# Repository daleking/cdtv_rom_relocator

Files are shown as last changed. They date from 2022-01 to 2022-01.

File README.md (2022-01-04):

# CDTV Extended ROM and CPU Relocator

I wanted to use a single 27C400 for the extended ROM in my CDTV because 2x
27C1000's are a pain.  A single socket for the rom also makes debugging easier
because I can use a single flashed based rom.  This means I can easily pop in
[CDTV Land's replacement ROM](https://cdtvland.com/os235/) and easily burn or
test future updates.

The second goal was to relocate the CPU socket in such a way to allow an
accelerator such as a TF536 or 020-TK to be installed without interferring with
caps and in such a way that by soldering everything together the case for the
CDTV could still be closed.

Hence the CDTV ROM Relocator was born.  It's a simple relocator with some
decoding logic for the extended ROM and a jumper to disable/enable the rom
(since JP15 on the motherboard only drives logic to the motherboard roms).

By trimming the CPU pins and soldering together a sandwich, the case can be
closed.

If you want to build one you can try the [gerbers from
here](CDTV_Reromlocator/gerbers_v3.zip).

## Photos

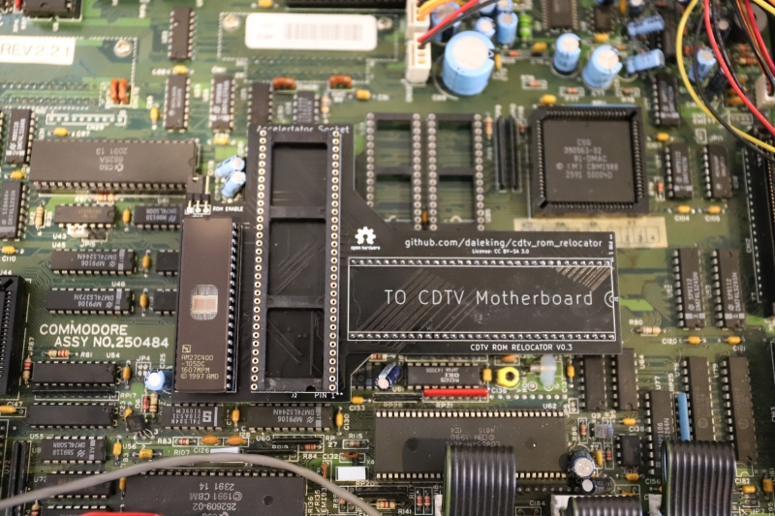
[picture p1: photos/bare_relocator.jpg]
bare relocator


This is the bare relocator with an empty 68000 socket.  Installing the original
68000 will still work and the case can still be closed.

**Note!**  If you install a socket for the accelerator you will likely not be able
to close the case.  I recommend soldering the accelerator directly to the
relocator but please do this at your own risk!

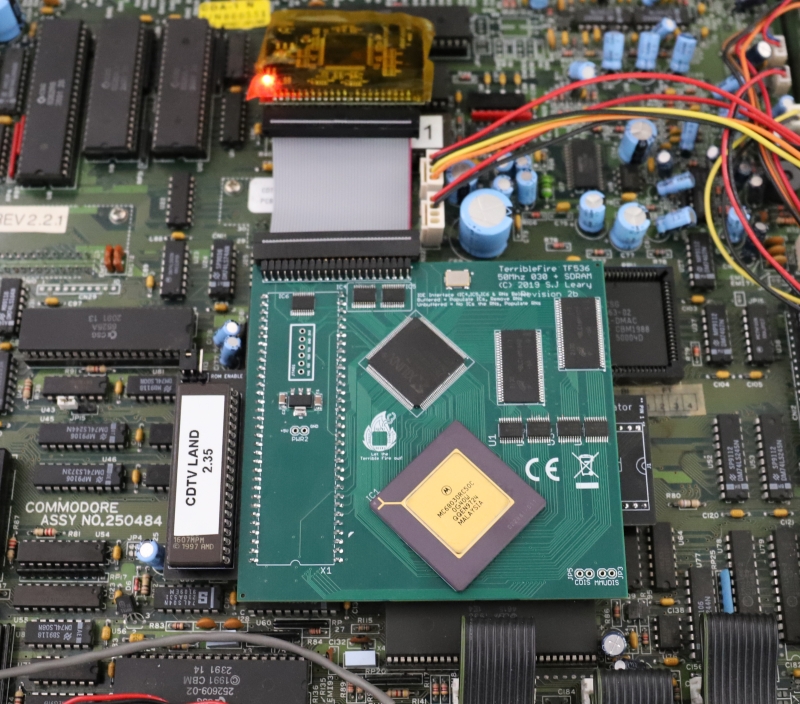
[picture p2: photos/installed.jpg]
installed


Here we have an installed TF536 and CDTV OS 2.35 on a single 27C400.

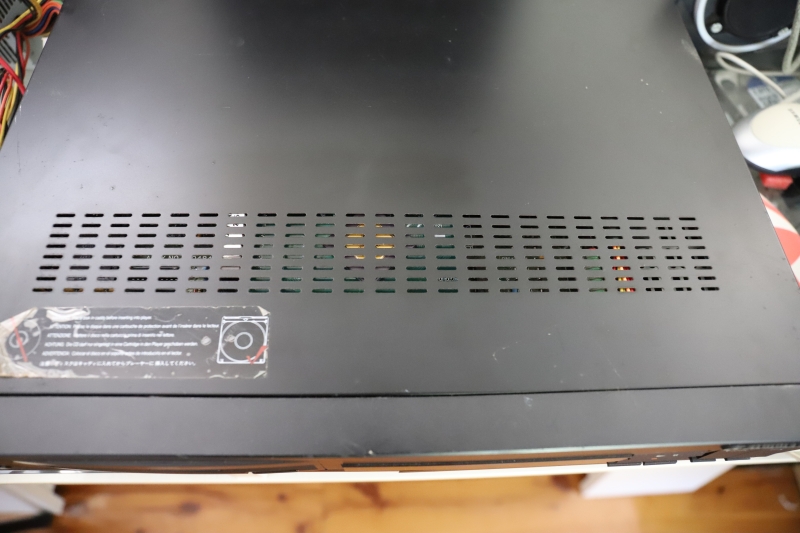
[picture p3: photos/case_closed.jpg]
case closed


Case closed!  The tallest component is the ROM, which still has a mm or two
before it touches the case.

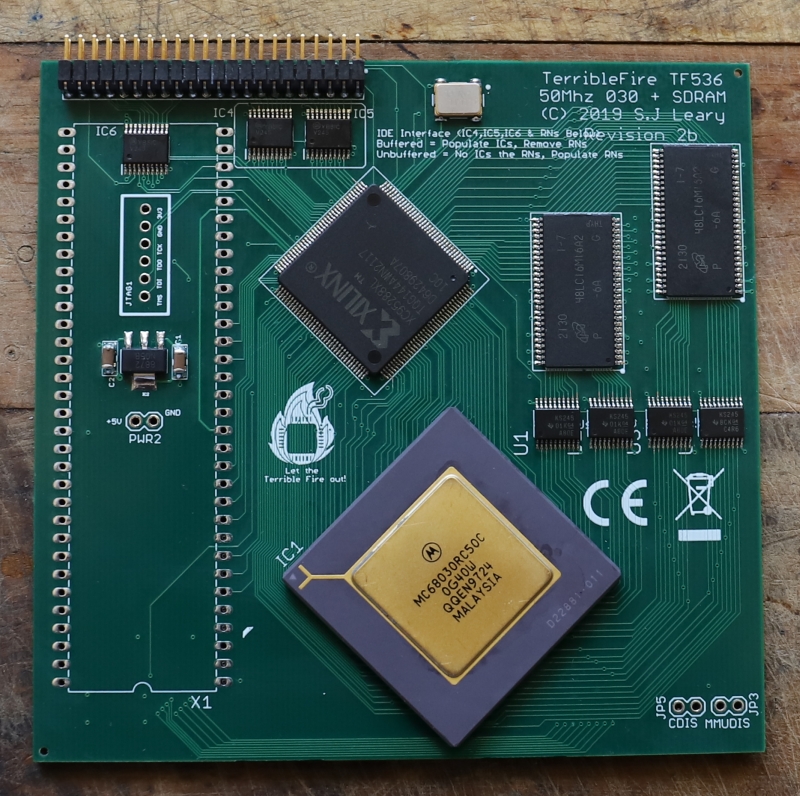
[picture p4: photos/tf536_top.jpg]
tf526 top


We'll need an accelerator.  I like the TF536 with the [firmware from
here](https://www.exxoshost.co.uk/forum/viewtopic.php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)
which disables the flashy boot rom on the TF536 (that is in the same address
space as the extended ROM).

You will also want a right angled IDE header, not a straight one.  This means
the cable connector is nice and flat.

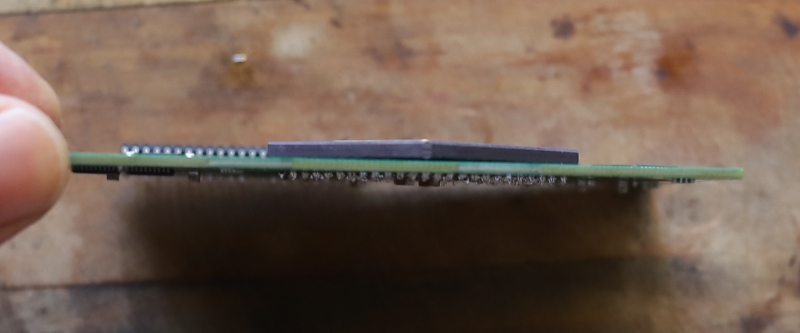
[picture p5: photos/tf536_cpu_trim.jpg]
tf536 cpu trim


You will want to solder down and trim the legs of your CPU.  In hindsight I
would raise the CPU of the board by a few mm and just solder the leads short.
There is enough height left for the CPU to sit a little proud but please do
test fit before soldering.

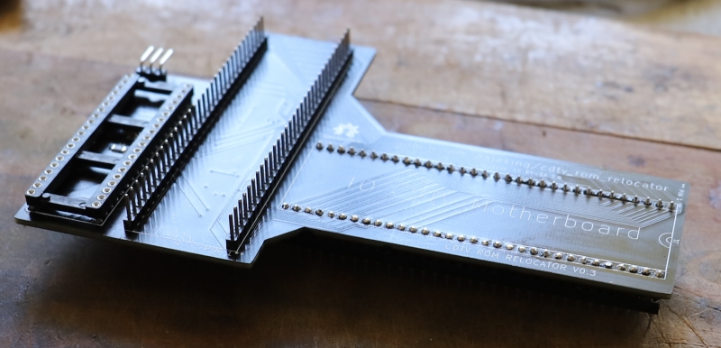
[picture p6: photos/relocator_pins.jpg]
relocator pins


I used regular pin strips between the relocator board and the TF536.  The
plastic at the bottom is the height I chose as a safe distance between the two
PCBs.

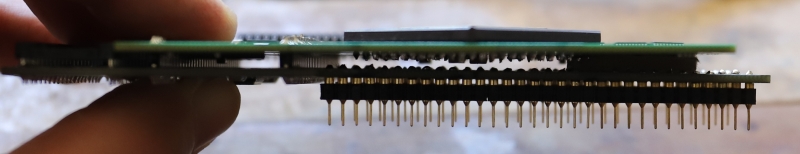
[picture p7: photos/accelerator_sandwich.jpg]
accelerator sandwich


Here they are just before soldering together.  Check there is nothing that will
short.  I used a bit of cardboard to keep everything spaced nicely and as a bit
of extra protection in case the boards got smooshed by the case.

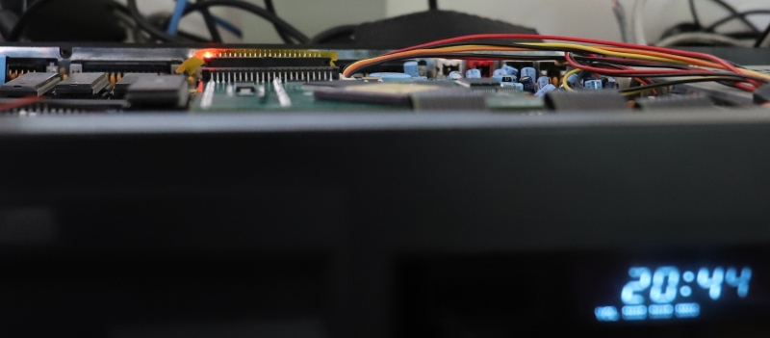
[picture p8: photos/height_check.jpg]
height check


Testing installed height.  In my case the ROM is the tallest component.  You
could try and find a lower profile DIP socket for the ROM.

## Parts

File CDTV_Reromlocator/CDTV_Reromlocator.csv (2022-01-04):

Reference | Quantity | Value | Footprint | Datasheet
C1 | 1 | 1uF | Capacitor_SMD:C_1206_3216Metric_Pad1.42x1.75mm_HandSolder | ~
C2 | 1 | 0.1uF | Capacitor_SMD:C_0805_2012Metric_Pad1.15x1.40mm_HandSolder | ~
C3 | 1 | 0.01uF | Capacitor_SMD:C_0805_2012Metric_Pad1.15x1.40mm_HandSolder | ~
C4 C5 | 2 | 0.33uF | Capacitor_SMD:C_1206_3216Metric_Pad1.42x1.75mm_HandSolder | ~
J1 | 1 | 68000 Socket | Package_DIP:DIP-64_W22.86mm_LongPads | ~
J2 | 1 | Relocated 68000 Socket | Package_DIP:DIP-64_W22.86mm_Socket | ~
JP15 | 1 | Jumper_3_Bridged12 | Connector_PinHeader_2.54mm:PinHeader_1x03_P2.54mm_Vertical | ~
R1 | 1 | 1K | Resistor_SMD:R_1206_3216Metric_Pad1.42x1.75mm_HandSolder | ~
U1 | 1 | 27C400 | Package_DIP:DIP-40_W15.24mm_Socket
U2 | 1 | 74HCT138 | Package_SO:SOIC-16_3.9x9.9mm_P1.27mm

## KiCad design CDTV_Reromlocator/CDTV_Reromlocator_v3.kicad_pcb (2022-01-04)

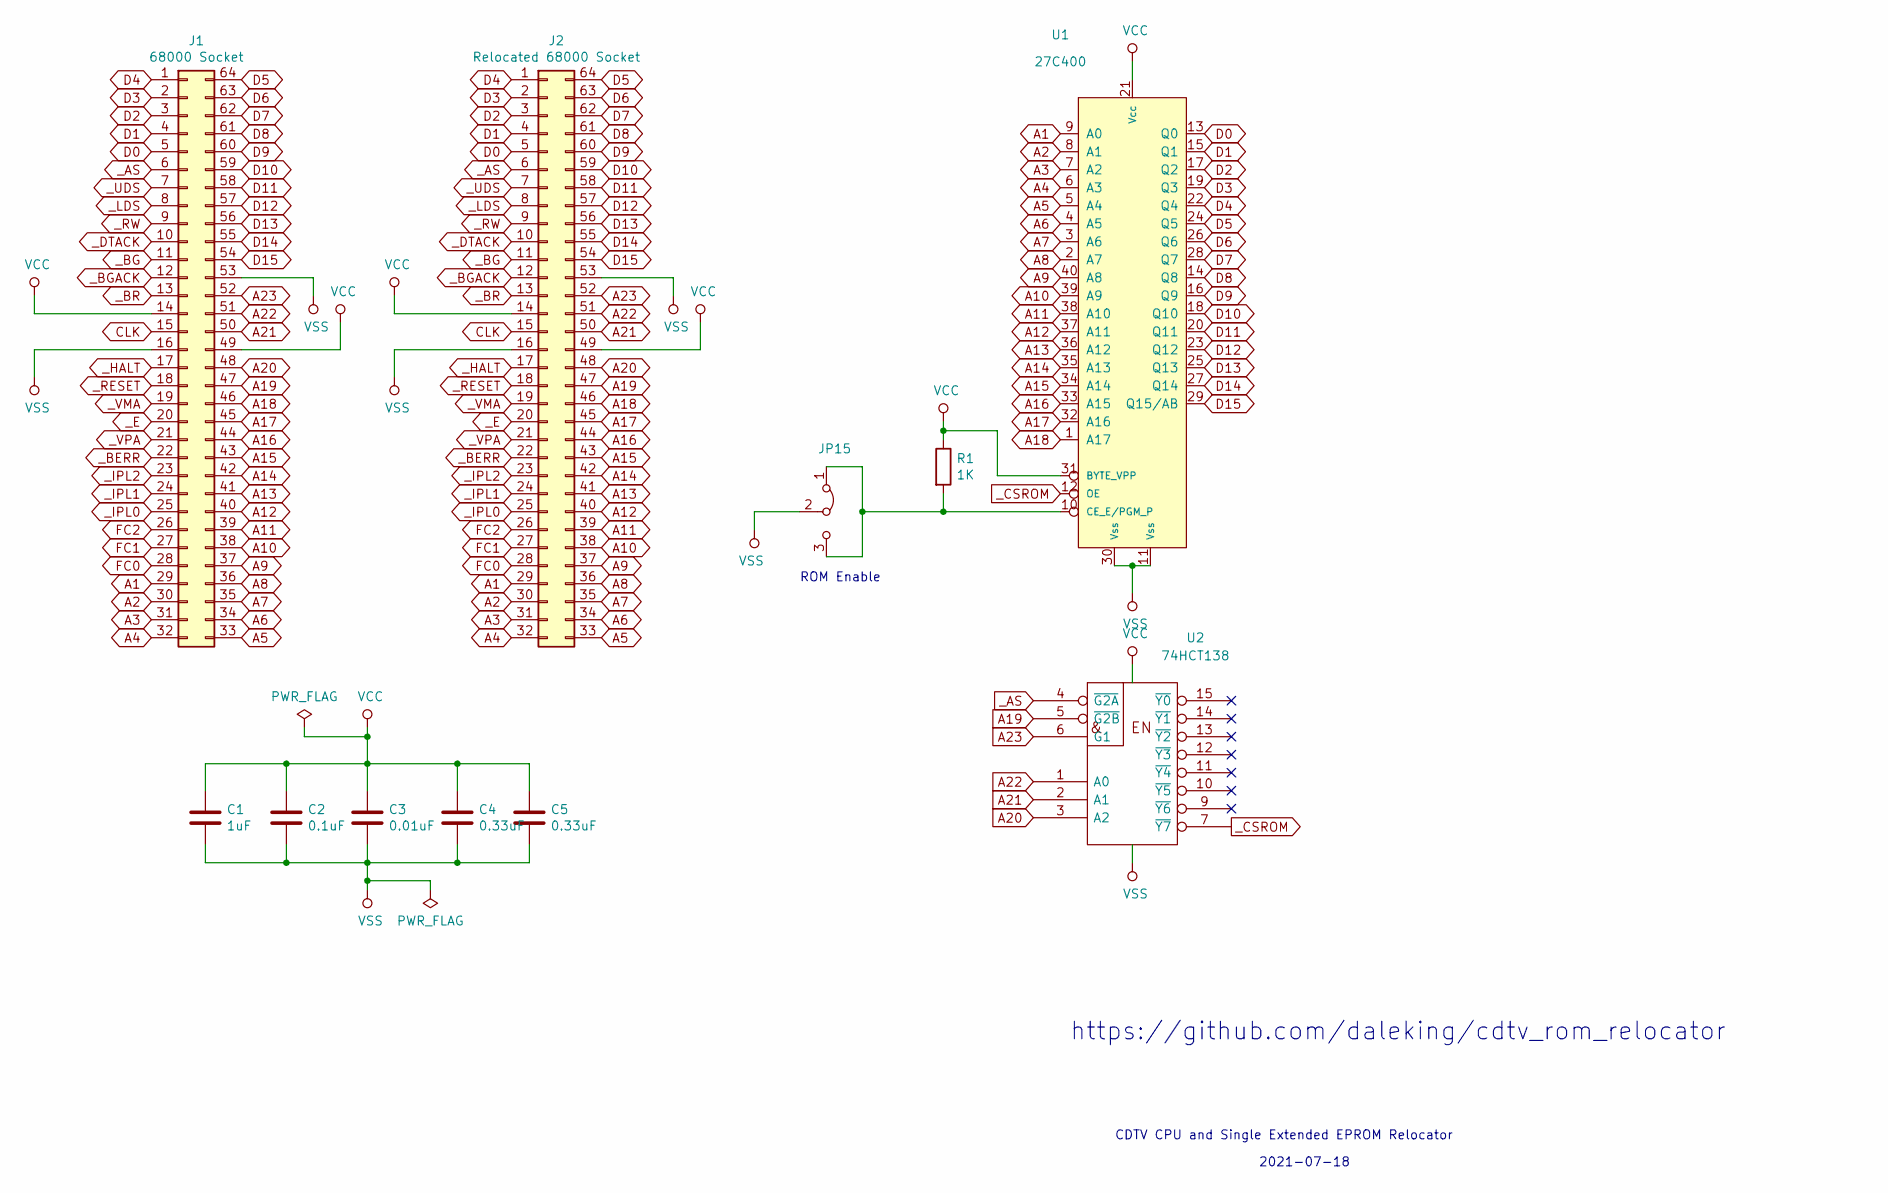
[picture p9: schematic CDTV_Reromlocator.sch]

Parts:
C1: 1uF; C_1206_3216Metric_Pad1.42x1.75mm_HandSolder
C2: 0.1uF; C_0805_2012Metric_Pad1.15x1.40mm_HandSolder
C3: 0.01uF; C_0805_2012Metric_Pad1.15x1.40mm_HandSolder
C4, C5: 0.33uF; C_1206_3216Metric_Pad1.42x1.75mm_HandSolder
J1: 68000 Socket; DIP-64_W22.86mm_Socket
J2: Relocated 68000 Socket; DIP-64_W22.86mm_Socket
JP15: Jumper_3_Bridged12; PinHeader_1x03_P2.54mm_Vertical
R1: 1K; R_1206_3216Metric_Pad1.42x1.75mm_HandSolder
U1: 27C400; DIP-40_W15.24mm_Socket
U2: 74HCT138; SOIC-16_3.9x9.9mm_P1.27mm

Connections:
A1: J1.29, J2.29, U1.9 (A0)
A2: J1.30, J2.30, U1.8 (A1)
A3: J1.31, J2.31, U1.7 (A2)
A4: J1.32, J2.32, U1.6 (A3)
A5: J1.33, J2.33, U1.5 (A4)
A6: J1.34, J2.34, U1.4 (A5)
A7: J1.35, J2.35, U1.3 (A6)
A8: J1.36, J2.36, U1.2 (A7)
A9: J1.37, J2.37, U1.40 (A8)
A10: J1.38, J2.38, U1.39 (A9)
A11: J1.39, J2.39, U1.38 (A10)
A12: J1.40, J2.40, U1.37 (A11)
A13: J1.41, J2.41, U1.36 (A12)
A14: J1.42, J2.42, U1.35 (A13)
A15: J1.43, J2.43, U1.34 (A14)
A16: J1.44, J2.44, U1.33 (A15)
A17: J1.45, J2.45, U1.32 (A16)
A18: J1.46, J2.46, U1.1 (A17)
A19: J1.47, J2.47, U2.5 (~G2B)
A20: J1.48, J2.48, U2.3 (A2)
A21: J1.50, J2.50, U2.2 (A1)
A22: J1.51, J2.51, U2.1 (A0)
A23: J1.52, J2.52, U2.6 (G1)
CLK: J1.15, J2.15
D0: J1.5, J2.5, U1.13 (Q0)
D1: J1.4, J2.4, U1.15 (Q1)
D2: J1.3, J2.3, U1.17 (Q2)
D3: J1.2, J2.2, U1.19 (Q3)
D4: J1.1, J2.1, U1.22 (Q4)
D5: J1.64, J2.64, U1.24 (Q5)
D6: J1.63, J2.63, U1.26 (Q6)
D7: J1.62, J2.62, U1.28 (Q7)
D8: J1.61, J2.61, U1.14 (Q8)
D9: J1.60, J2.60, U1.16 (Q9)
D10: J1.59, J2.59, U1.18 (Q10)
D11: J1.58, J2.58, U1.20 (Q11)
D12: J1.57, J2.57, U1.23 (Q12)
D13: J1.56, J2.56, U1.25 (Q13)
D14: J1.55, J2.55, U1.27 (Q14)
D15: J1.54, J2.54, U1.29 (Q15/AB)
FC0: J1.28, J2.28
FC1: J1.27, J2.27
FC2: J1.26, J2.26
GND: C1.2, C2.2, C3.2, C4.2, C5.2, J1.16, J1.53, J2.16, J2.53, JP15.2 (C), U1.11 (Vss), U1.30 (Vss), U2.8 (GND)
unnamed: JP15.1 (A), JP15.3 (B), R1.2, U1.10 (CE_E/PGM_P)
VCC: C1.1, C2.1, C3.1, C4.1, C5.1, J1.14, J1.49, J2.14, J2.49, R1.1, U1.21 (Vcc), U1.31 (BYTE_VPP), U2.16 (VCC)
_AS: J1.6, J2.6, U2.4 (~G2A)
_BERR: J1.22, J2.22
_BG: J1.11, J2.11
_BGACK: J1.12, J2.12
_BR: J1.13, J2.13
_CSROM: U1.12 (OE), U2.7 (~Y7)
_DTACK: J1.10, J2.10
_E: J1.20, J2.20
_HALT: J1.17, J2.17
_IPL0: J1.25, J2.25
_IPL1: J1.24, J2.24
_IPL2: J1.23, J2.23
_LDS: J1.8, J2.8
_RESET: J1.18, J2.18
_RW: J1.9, J2.9
_UDS: J1.7, J2.7
_VMA: J1.19, J2.19
_VPA: J1.21, J2.21

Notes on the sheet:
CDTV CPU and Single Extended EPROM Relocator
2021-07-18
https://github.com/daleking/cdtv_rom_relocator
ROM Enable

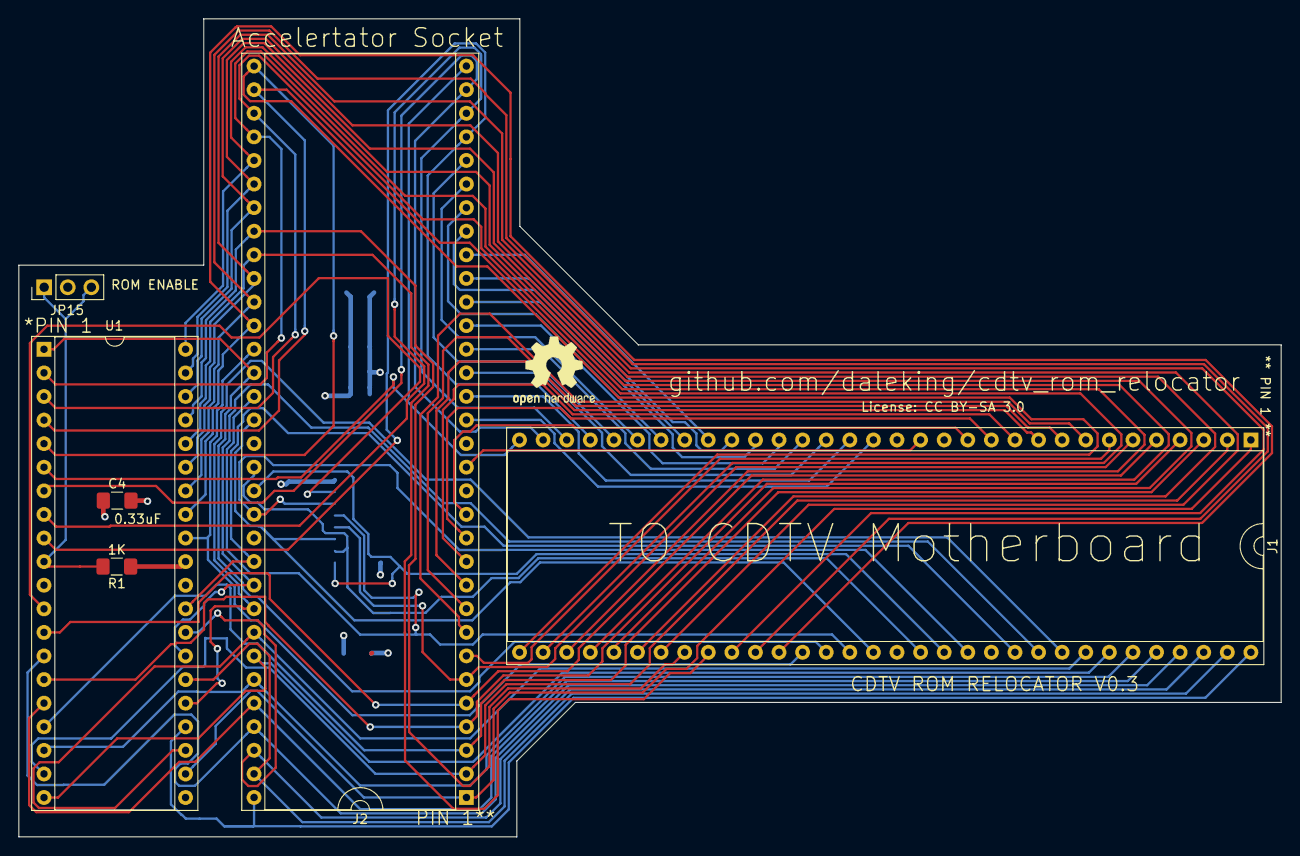
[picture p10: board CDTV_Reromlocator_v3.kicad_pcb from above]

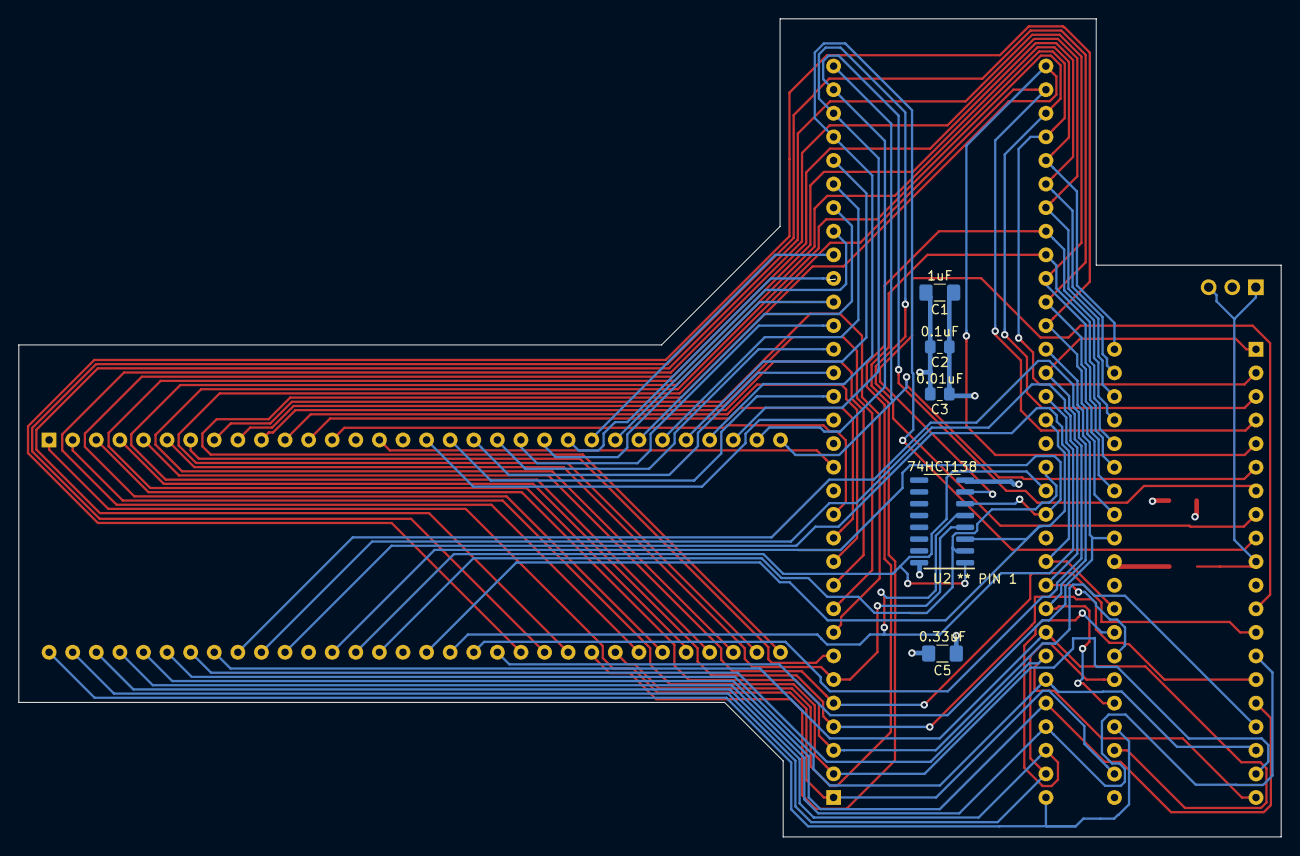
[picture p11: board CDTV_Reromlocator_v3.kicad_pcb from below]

Board: 4 copper layers, 135.9 x 88.1 mm, 11 parts (5 on the bottom side), 64 nets.

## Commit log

2022-01-04 initial checkin
    [CDTV_Reromlocator.sch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]
2022-01-04 add .csv
    [CDTV_Reromlocator.csv]

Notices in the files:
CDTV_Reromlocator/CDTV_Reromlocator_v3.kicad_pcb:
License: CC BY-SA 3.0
